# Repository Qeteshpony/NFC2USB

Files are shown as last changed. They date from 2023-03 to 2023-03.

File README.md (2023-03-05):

# NFC2USB



3D Render

[Documentation](https://qeteshpony.github.io/NFC2USB)

Connect an RC522 based NFC-Reader to your computer using USB

The project is based around a Raspberry Pi [RP2040](https://www.raspberrypi.com/documentation/microcontrollers/rp2040.html) microcontroller. It would have been possible to solve this with a much simpler controller but availability and pricing at the time of development as well as ease of use made the RP2040 with built in USB the best choice. 

The board is designed using KiCAD 6 with production and assembly by JLCPCB in mind. All parts are selected to be available from JLCPCB at the time of writing and as many parts as possible are used from their basic library.

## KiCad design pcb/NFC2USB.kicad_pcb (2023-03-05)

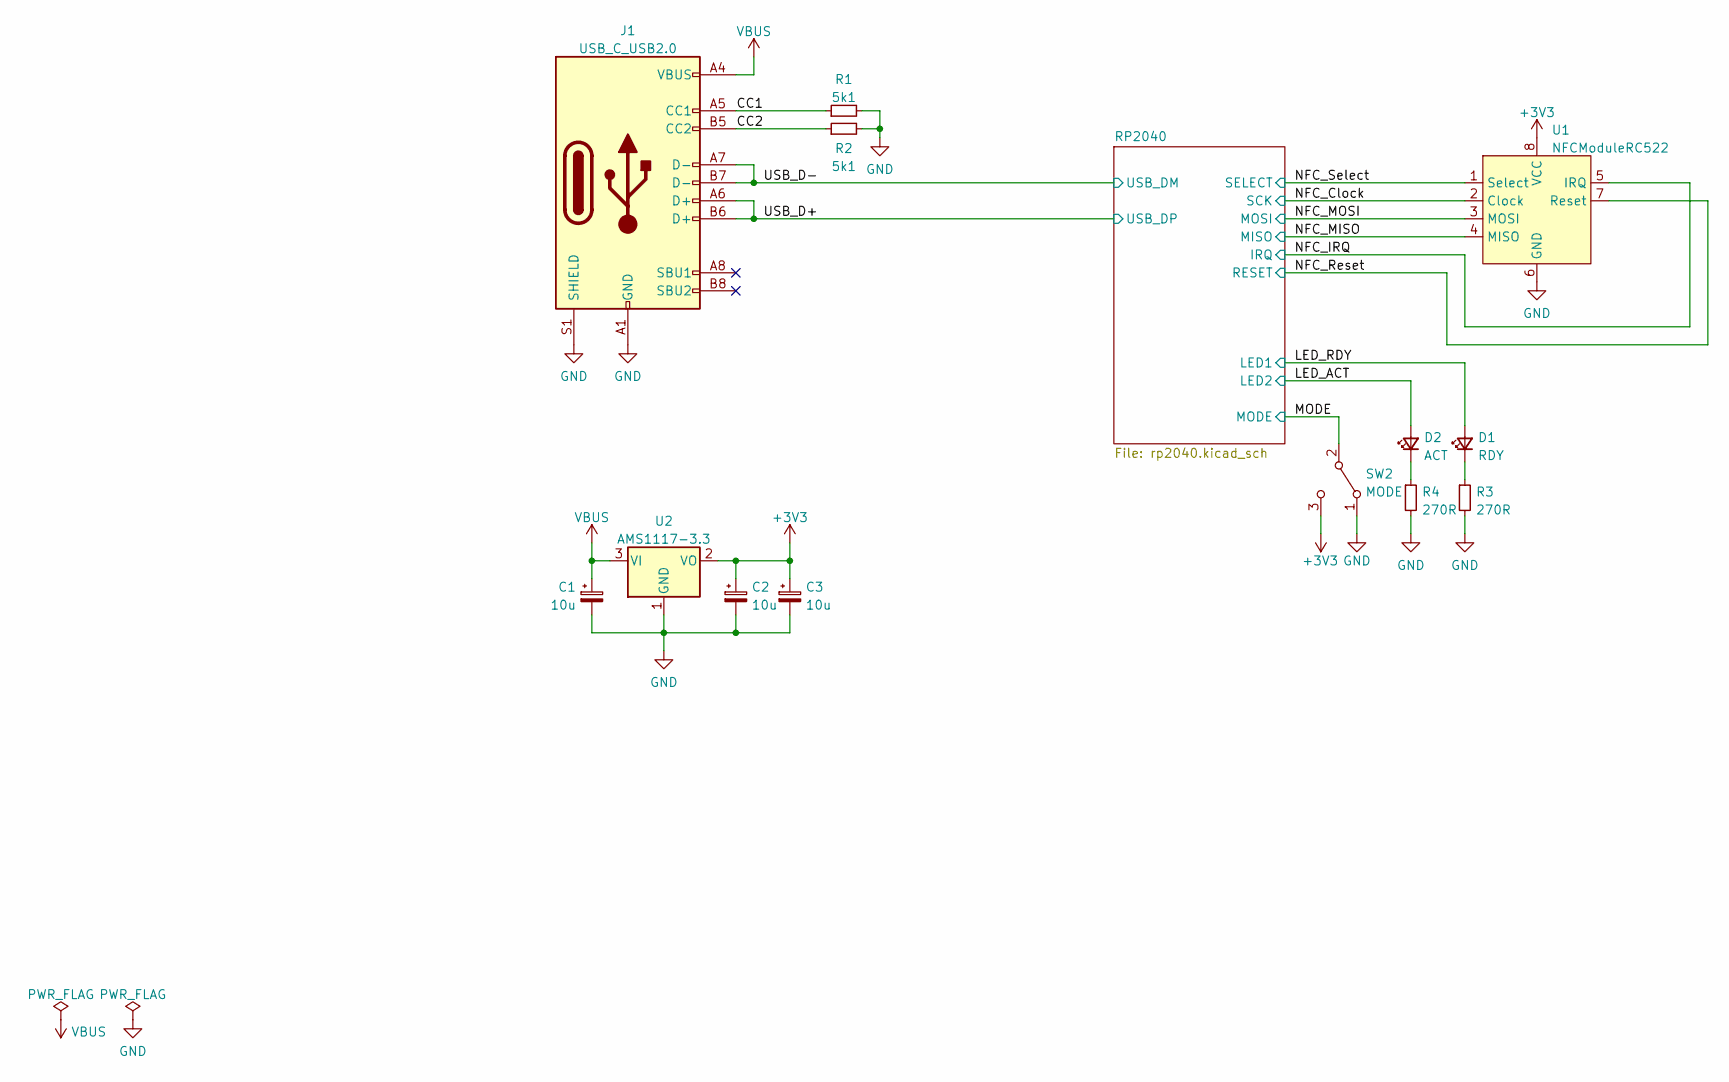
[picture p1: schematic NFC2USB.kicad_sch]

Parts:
C1, C2, C3: 10u; CP_EIA-3216-18_Kemet-A; LCSC C7171
D1: RDY; LED_0603_1608Metric; LCSC C72043
D2: ACT; LED_0603_1608Metric; LCSC C72038
J1: USB_C_USB2.0; USB_C_Receptacle_HRO_TYPE-C-31-M-12; LCSC C2894897
R1, R2: 5k1; R_0402_1005Metric; LCSC C25905
R3, R4: 270R; R_0603_1608Metric; LCSC C22966
SW2: MODE; SW_SPDT_PCM12; LCSC C431541
U1: NFCModuleRC522; PinSocket_1x08_P2.54mm_Vertical
U2: AMS1117-3.3; SOT-223-3_TabPin2; LCSC C6186

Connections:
+3V3: C2.1, C3.1, SW2.3 (C), U1.8 (VCC), U2.2 (VO); also elsewhere on the board
/CC1: J1.A5 (CC1), R1.1
/CC2: J1.B5 (CC2), R2.1
/LED_ACT: D2.2 (A); also elsewhere on the board
/LED_RDY: D1.2 (A); also elsewhere on the board
/MODE: SW2.2 (B); also elsewhere on the board
/NFC_Clock: U1.2 (Clock); also elsewhere on the board
/NFC_IRQ: U1.5 (IRQ); also elsewhere on the board
/NFC_MISO: U1.4 (MISO); also elsewhere on the board
/NFC_MOSI: U1.3 (MOSI); also elsewhere on the board
/NFC_Reset: U1.7 (Reset); also elsewhere on the board
/NFC_Select: U1.1 (Select); also elsewhere on the board
/USB_D+: J1.A6 (D+), J1.B6 (D+); also elsewhere on the board
/USB_D-: J1.A7 (D-), J1.B7 (D-); also elsewhere on the board
GND: C1.2, C2.2, C3.2, J1.A1 (GND), J1.A12 (GND), J1.B1 (GND), J1.B12 (GND), J1.S1 (SHIELD), R1.2, R2.2, R3.2, R4.2, SW2.1 (A), U1.6 (GND), U2.1 (GND); also elsewhere on the board
unnamed: D1.1 (K), R3.1
unnamed: D2.1 (K), R4.1
VBUS: C1.1, J1.A4 (VBUS), J1.A9 (VBUS), J1.B4 (VBUS), J1.B9 (VBUS), U2.3 (VI)

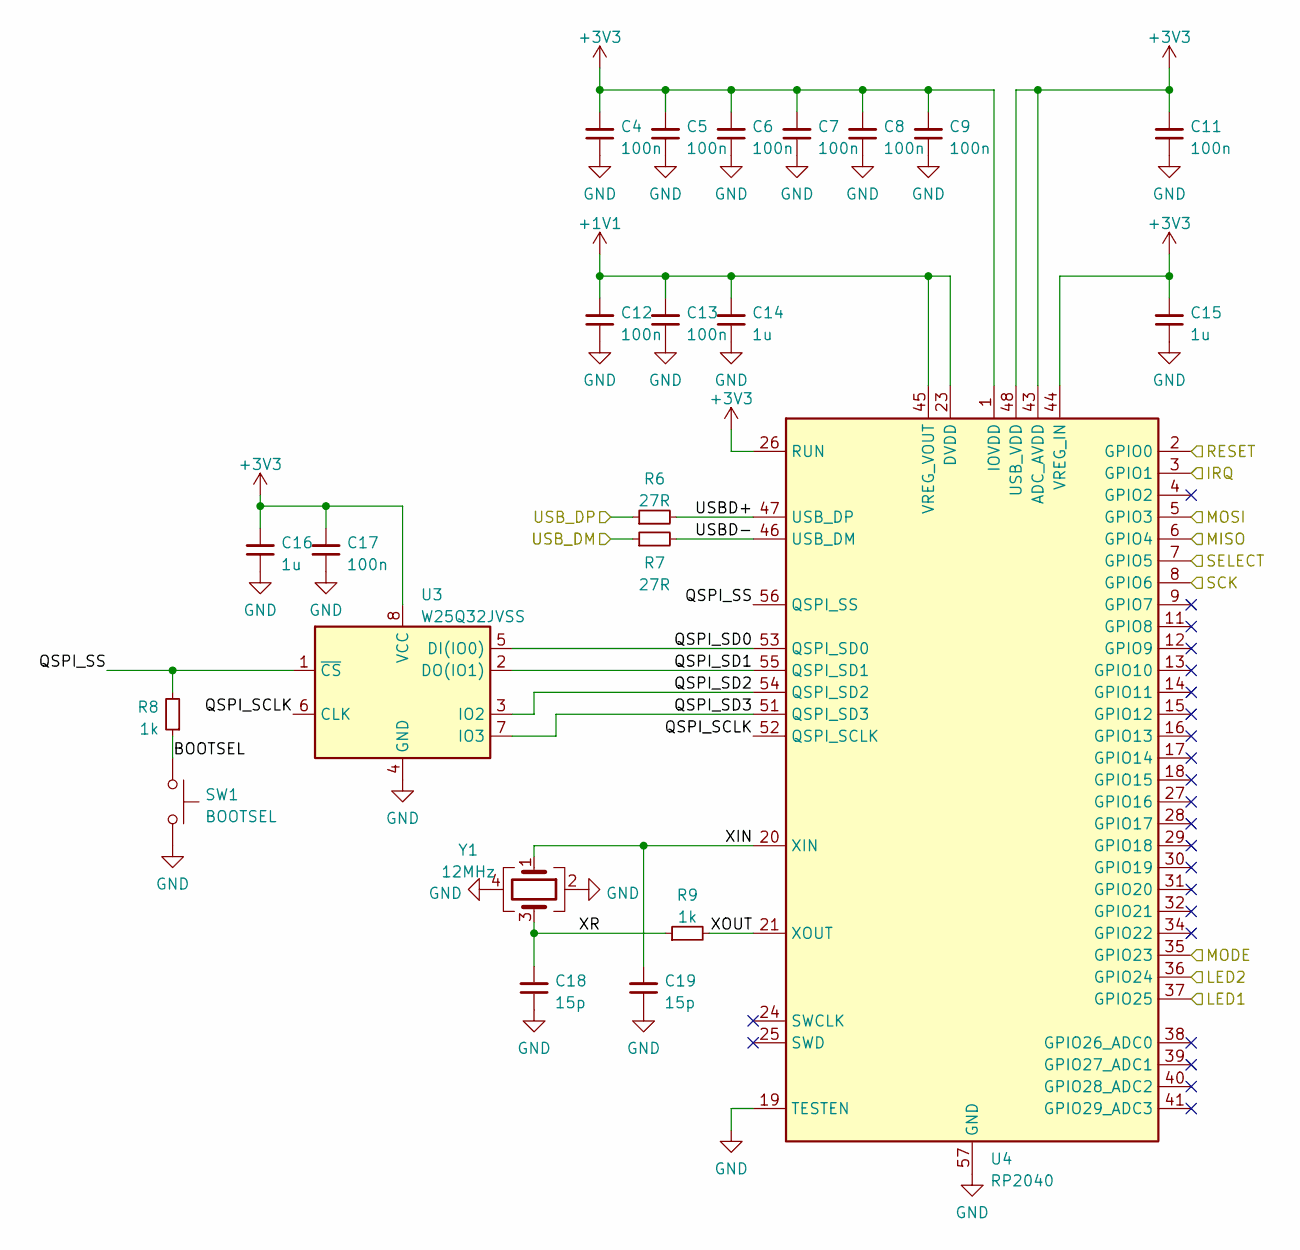
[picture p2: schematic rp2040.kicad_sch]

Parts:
C4, C5, C6, C7, C8, C9, C11, C12, C13, C17: 100n; C_0402_1005Metric; LCSC C1525
C14, C15, C16: 1u; C_0402_1005Metric; LCSC C52923
C18, C19: 15p; C_0402_1005Metric; LCSC C1548
R6, R7: 27R; R_0402_1005Metric; LCSC C25100
R8, R9: 1k; R_0402_1005Metric; LCSC C11702
SW1: BOOTSEL; SW_SPST_TL3342; LCSC C318884
U3: W25Q32JVSS; SOIC-8_5.23x5.23mm_P1.27mm; LCSC C179173
U4: RP2040; QFN-56-1EP_7x7mm_P0.4mm_EP3.2x3.2mm; LCSC C2040
Y1: 12MHz; Crystal_SMD_3225-4Pin_3.2x2.5mm; LCSC C9002

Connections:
+1V1: C12.2, C13.2, C14.2, U4.23 (DVDD), U4.45 (VREG_VOUT), U4.50 (DVDD)
+3V3: C4.2, C5.2, C6.2, C7.2, C8.2, C9.2, C11.2, C15.2, C16.2, C17.2, U3.8 (VCC), U4.1 (IOVDD), U4.10 (IOVDD), U4.22 (IOVDD), U4.26 (RUN), U4.33 (IOVDD), U4.42 (IOVDD), U4.43 (ADC_AVDD), U4.44 (VREG_IN), U4.48 (USB_VDD), U4.49 (IOVDD); also elsewhere on the board
/LED_ACT: U4.36 (GPIO24); also elsewhere on the board
/LED_RDY: U4.37 (GPIO25); also elsewhere on the board
/MODE: U4.35 (GPIO23); also elsewhere on the board
/NFC_Clock: U4.8 (GPIO6); also elsewhere on the board
/NFC_IRQ: U4.3 (GPIO1); also elsewhere on the board
/NFC_MISO: U4.6 (GPIO4); also elsewhere on the board
/NFC_MOSI: U4.5 (GPIO3); also elsewhere on the board
/NFC_Reset: U4.2 (GPIO0); also elsewhere on the board
/NFC_Select: U4.7 (GPIO5); also elsewhere on the board
/RP2040/BOOTSEL: R8.1, SW1.1
/RP2040/QSPI_SCLK: U3.6 (CLK), U4.52 (QSPI_SCLK)
/RP2040/QSPI_SD0: U3.5 (DI(IO0)), U4.53 (QSPI_SD0)
/RP2040/QSPI_SD1: U3.2 (DO(IO1)), U4.55 (QSPI_SD1)
/RP2040/QSPI_SD2: U3.3 (IO2), U4.54 (QSPI_SD2)
/RP2040/QSPI_SD3: U3.7 (IO3), U4.51 (QSPI_SD3)
/RP2040/QSPI_SS: R8.2, U3.1 (~CS), U4.56 (QSPI_SS)
/RP2040/USBD+: R6.2, U4.47 (USB_DP)
/RP2040/USBD-: R7.2, U4.46 (USB_DM)
/RP2040/XIN: C19.2, U4.20 (XIN), Y1.1
/RP2040/XOUT: R9.2, U4.21 (XOUT)
/RP2040/XR: C18.2, R9.1, Y1.3
/USB_D+: R6.1; also elsewhere on the board
/USB_D-: R7.1; also elsewhere on the board
GND: C4.1, C5.1, C6.1, C7.1, C8.1, C9.1, C11.1, C12.1, C13.1, C14.1, C15.1, C16.1, C17.1, C18.1, C19.1, SW1.2, U3.4 (GND), U4.19 (TESTEN), U4.57 (GND), Y1.2, Y1.4; also elsewhere on the board

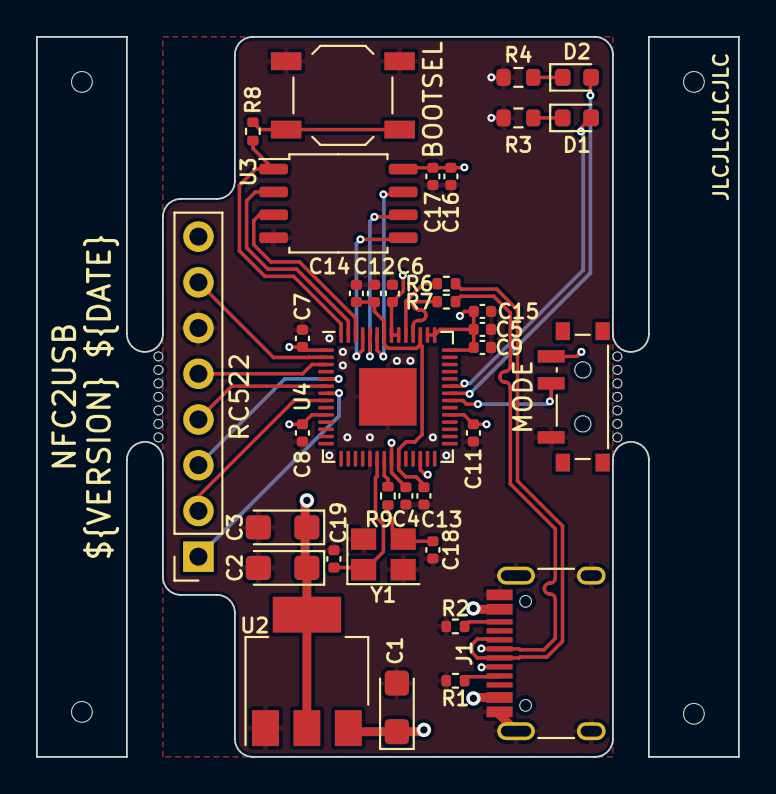
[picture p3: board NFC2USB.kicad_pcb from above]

Board: 4 copper layers, 39.0 x 40.0 mm, 38 parts (0 on the bottom side), 31 nets.

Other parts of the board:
mouse-bite-2mm-slot, mouse-bite-2mm-slot#2: VAL**; mouse-bite-2x5mm-slot-onesided

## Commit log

2023-03-01 fix: add PWR_FLAGs
    [NFC2USB.kicad_sch, esp32-s2.kicad_sch]
2023-03-01 chore: update reference for power nets
    [NFC2USB.kicad_sch, esp32-s2.kicad_sch]
2023-03-01 style: (re)move overlapping silkscreen objects
    [NFC2USB.kicad_pcb]
2023-03-01 style: remove more overlapping silkscreen
    [NFC2USB.kicad_pcb]
2023-03-01 style: hide pin sockets from 3d-render
    [NFC2USB.kicad_pcb]
2023-03-04 feat: change from ESP32 to RP2040
    Changing the Microcontroller to RP2040 because of price, availability and ease of use
    [NFC2USB.kicad_pcb, NFC2USB.kicad_sch, esp32-s2.kicad_sch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]
2023-03-04 style: wrong 3d-model
    [NFC2USB.kicad_pcb]
2023-03-04 style: 3d-model rotation
    [NFC2USB.kicad_pcb]
2023-03-05 style: board cleanup
    [NFC2USB.kicad_pcb]
